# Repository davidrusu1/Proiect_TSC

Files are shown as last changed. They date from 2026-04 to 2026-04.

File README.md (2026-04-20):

# InkTime — Smartwatch Open Source

Un smartwatch proiectat de la zero — schematic, PCB 4 straturi, model 3D complet — bazat pe nRF52840 și un display E-Paper cu consum zero în standby.

---

## Despre proiect

InkTime este un ceas inteligent construit integral custom: fiecare componentă a fost aleasă, plasată și rutată manual, de la primul simbol în schematic până la modelul 3D pregătit pentru fabricație.

Tehnologia centrală este display-ul **E-Paper (e-ink)** — după ce afișează o imagine, o menține fără niciun consum de energie. Combinat cu modul deep sleep al nRF52840 (~1.5μA), dispozitivul poate funcționa zile întregi dintr-o baterie LiPo mică.

---

## Ce conține placa

| Subsistem | Componentă | Rol |
|---|---|---|
| Microcontroller | nRF52840 | Cortex-M4 64MHz, BT 5.0, USB nativ |
| Display | E-Paper via SPI | Afișaj fără consum în standby |
| Mișcare | BMA423 | Accelerometru 3 axe, step counter, wake-on-wrist |
| Încărcare | BQ25180 | LiPo charger programabil I2C, 5mA–1A |
| Alimentare | RT6160 | Buck-Boost 3.3V stabil indiferent de tensiunea bateriei |
| Fuel Gauge | MAX17048 | Monitorizare baterie ModelGauge, fără shunt rezistor |
| Feedback haptic | DRV2605 | Driver haptic I2C, 123 efecte ERM/LRA |
| USB | KH-TYPE-C-16P + USBLC6 | Conector USB-C cu protecție ESD ±15kV |
| Butoane | EVP-AKE31A ×3 | Butoane tactile SMD ultra-subțiri |
| RF | 2450AT18B100E | Antenă SMD 2.45GHz pentru Bluetooth |

---

## Diagrama bloc a sistemului

```
USB-C (5V)
    │
    ▼
┌─────────┐    VBUS      ┌──────────────┐
│  ESD    │─────────────▶│  BQ25180     │ LiPo Charger
│USBLC6   │              │  (I2C 0x6A)  │◀─── Baterie LiPo
└────┬────┘              └──────┬───────┘
     │ D+/D−                    │ VBAT
     │                          ▼
     │                   ┌──────────────┐
     │                   │  MAX17048    │ Fuel Gauge
     │                   │  (I2C 0x36)  │
     │                   └──────┬───────┘
     │                          │ VBAT
     │                          ▼
     │                   ┌──────────────┐
     │                   │   RT6160     │ Buck-Boost DC/DC
     │                   │  (I2C 0x62)  │─── 3V3 ──────────┐
     │                   └──────────────┘                   │
     │                                                      │
     └──────────────────────────────────────────────────────▼
                                                    ┌──────────────────┐
                  ┌── SPI ──▶ E-Paper Display       │                  │
                  │                                  │    nRF52840      │
                  ├── I2C ──▶ BMA423  (0x18)        │    Cortex-M4     │
                  │       ──▶ DRV2605 (0x5A)        │    64MHz / BT5.0 │
                  │       ──▶ BQ25180 (0x6A)        │                  │
                  │       ──▶ RT6160  (0x62)        └────────┬─────────┘
                  │       ──▶ MAX17048(0x36)                 │
                  │                                          │ GPIO
                  ├── SWD ──▶ TC2030-IDC                     │
                  │                                          ▼
                  └── USB ──▶ (intern nRF52840)      Butoane ×3 / IMU INT / HAPTIC_EN
```

---

## BOM — Bill of Materials

| Ref | Part Number | Descriere | Qty |
|---|---|---|---|
| U1 | nRF52840-QIAA-R | MCU ARM Cortex-M4, BT 5.0, USB 2.0, 1MB Flash | 1 |
| IC1 | BQ25180YBGR | LiPo charger liniar 1A I2C, 8-DSBGA | 1 |
| IC2 | DRV2605YZFR | Haptic driver ERM/LRA I2C 123 efecte, 9-BGA | 1 |
| IC3 | BMA423 | Accelerometru MEMS triaxial 12-bit, LGA-12 | 1 |
| U3 | MAX17048G+T10 | Fuel gauge ModelGauge 1-cell, SOT-23-6 | 1 |
| IC9 | RT6160AWSC | Buck-Boost DC/DC 800mA I2C, 15-WL-CSP | 1 |
| D3 | USBLC6-2SC6Y | TVS ESD ±15kV bidirecțional USB, SOT-23-6 | 1 |
| J4 | KH-TYPE-C-16P | Conector USB-C 16 pini SMD | 1 |
| J1 | 503480-2400 | Conector FPC/FFC 0.5mm pas 24 circuite | 1 |
| J2 | TC2030-IDC | Tag-Connect SWD 6 pini footprint-only | 1 |
| Q2 | DMG2305UX-7 | P-MOSFET 20V/4.2A, SOT-23 | 1 |
| Q3 | SI1308EDL-T1-GE3 | N-MOSFET 30V/1.5A, SC-70 | 1 |
| D1,D2,D5 | MBR0530 | Schottky 30V/500mA, SOD-123 | 3 |
| SW_* | EVP-AKE31A | Buton tactil SMD ultra-subțire Panasonic | 3 |
| ANT1 | 2450AT18B100E | Antenă SMD 2.45GHz Johanson | 1 |
| L7 | FTC252012SR47MBCA | Inductor 0.47μH SMD 2016 | 1 |
| L5 | 744043680 | Inductor 68μH WE-TPC SMD | 1 |
| X1 | SXT21410EC27-32.000M | Cristal SMD 32MHz | 1 |
| X2 | NX3215SA-32.768K | Cristal RTC 32.768kHz 3215 SMD | 1 |
| Cx | GJM0335C1ER33WB01D / GRM011R60J152KE01L | Condensatoare SMD 0201/0402, 1pF–22μF | ~50 |
| Rx | ERA-1AEB / CPF0201 | Rezistoare SMD 0201, 2.2Ω–10kΩ | ~15 |
| TP_* | — | Test pad SMD | 14 |

---

## Hardware în detaliu

### Cum circulă energia

Bateria LiPo (3.7–4.2V) furnizează tensiunea de intrare pentru regulatorul **RT6160**, care generează un rail stabil de 3.3V pentru întreaga placă. La conectarea USB-C, VBUS (5V) ajunge direct la **BQ25180**, care preia controlul încărcării bateriei independent de restul sistemului. nRF52840 monitorizează în permanență cele două stări: prezența USB prin semnalul CHARGER_PG și nivelul bateriei prin **MAX17048** pe magistrala I2C.

Componentele cu consum ridicat — display-ul E-Paper și driverul haptic — sunt controlate fiecare printr-un MOSFET (Q2/Q3), permițând nRF52840 să le întrerupă complet alimentarea când nu sunt necesare.

---

### Magistrala I2C — 5 periferice pe aceleași fire

| Componentă | Adresă I2C | Funcție |
|---|---|---|
| BQ25180 | 0x6A | Reglează curentul și tensiunea de încărcare |
| RT6160 | 0x62 | Ajustează tensiunea de ieșire la nevoie |
| BMA423 | 0x18 | Furnizează date accelerometru și numără pași |
| MAX17048 | 0x36 | Raportează procentul de baterie și tensiunea celulei |
| DRV2605 | 0x5A | Selectează și redă efecte tactile |

Clock pe **P0.06**, date pe **P0.07**. Rezistoare de pull-up pe ambele linii.

---

### SPI — Display E-Paper

Comunicație unidirecțională spre display — nu există linie MISO deoarece displayul nu transmite date înapoi. Frecvență maximă 4MHz. Pe lângă SCK și MOSI, display-ul necesită 3 semnale GPIO suplimentare: **DC** (Data/Command), **RST** (reset hardware) și **BUSY** (MCU-ul așteaptă când displayul procesează un refresh).

---

### SWD — Programare și debug

Conectorul **TC2030-IDC** (Tag-Connect, fără pini fizici pe PCB) expune SWDIO, SWDCLK, SWO și RESET. Nu ocupă înălțime în ansamblu — cablul de programare se atașează temporar prin spring pins pe pad-urile PCB-ului.

---

### Bluetooth și antenă

Antena **2450AT18B100E** este o antenă SMD ceramică pentru 2.4GHz, plasată spre exteriorul plăcii cu un decupaj în substrat sub ea. Decupajul elimină FR4-ul (material cu pierderi dielectrice la 2.4GHz) din zona de radiație, îmbunătățind câștigul și adaptarea de impedanță a antenei. Cristalul de 32MHz furnizează referința de frecvență pentru modulul radio.

---

### Cristalul de 32.768kHz — RTC în sleep

Al doilea oscilator alimentează timer-ul RTC al nRF52840 și rămâne activ inclusiv în deep sleep. Permite dispozitivului să mențină ora exactă și să se trezească la intervale precise fără a ține procesorul activ.

---

### BMA423 — Mai mult decât un accelerometru

BMA423 dispune de un procesor intern dedicat pentru algoritmii de step counting și wake-on-wrist, care rulează independent de nRF52840. La detectarea mișcării specifice ridicării mâinii, trimite o întrerupere pe **P1.08 (IMU_INT1)** care trezește MCU-ul din deep sleep în microsecunde. Consum în această stare: 0.9μA.

---

### Estimare consum și autonomie

| Scenariu | Curent estimat |
|---|---|
| nRF52840 TX Bluetooth activ | 6.26 mA |
| nRF52840 RX Bluetooth activ | 4.82 mA |
| Refresh display E-Paper | ~26 mA (câteva secunde) |
| BMA423 monitorizare continuă | 130 μA |
| MAX17048 fuel gauge activ | 23 μA |
| DRV2605 vibrație activă | 5 mA |
| nRF52840 deep sleep + RTC + BMA low-power | ~50–100 μA |

Consum mediu în utilizare normală (BT conectat periodic, refresh display la fiecare minut, IMU activ): **6–8 mA la 3.3V**.

Cu o baterie LiPo de **300mAh**: autonomie estimată **35–50 ore**.

---

## Alocarea pinilor nRF52840

### Display E-Paper (SPI)

| Pin MCU | Semnal | Direcție | Descriere |
|---|---|---|---|
| P0.02 / AIN0 | SCK | OUT | Clock SPI pentru display |
| P0.03 / AIN1 | MOSI | OUT | Date seriale spre display |
| P0.05 / AIN3 | EPD_CS | OUT | Chip select, activ LOW |
| P0.15 | EPD_RST | OUT | Reset hardware display, activ LOW |
| P0.16 | EPD_DC | OUT | LOW = comandă, HIGH = date |
| P0.17 | EPD_BUSY | IN | HIGH când displayul procesează |

### Periferice I2C

| Pin MCU | Semnal | Descriere |
|---|---|---|
| P0.06 | SCL | Clock comun pentru toate perifericele I2C |
| P0.07 | SDA | Date bidirecționale I2C |
| P0.08 | IMU_INT2 | Întrerupere secundară BMA423 (step counter) |
| P1.08 | IMU_INT1 | Întrerupere primară BMA423 (wake-on-wrist) |
| P0.10 / NFC2 | FUELGAUGE_ALT | Alarmă MAX17048 la baterie scăzută |
| P0.11 | CHARGER_PG | Power Good BQ25180 — HIGH când USB e valid |
| P0.12 | HAPTIC_EN | Enable DRV2605, activ HIGH |

### Butoane

| Pin MCU | Semnal | Descriere |
|---|---|---|
| P0.13 | BTN_UP | Buton sus (navigare meniu) |
| P0.14 | BTN_ENT | Buton enter / confirmare |
| P1.02 | BTN_DN | Buton jos (navigare meniu) |

### USB, SWD și ceasuri

| Pin MCU | Semnal | Interfață | Descriere |
|---|---|---|---|
| D+ | USB_DP | USB | Linie diferențială pozitivă, prin ESD |
| D− | USB_DM | USB | Linie diferențială negativă, prin ESD |
| VBUS | 5V_USB | PWR | Detecție USB prezent → BQ25180 |
| SWDIO | SWDIO | SWD | Date programare/debug |
| SWDCLK | SWDCLK | SWD | Clock programare/debug |
| SWO | SWO | SWD | Serial Wire Output (trace) |
| P0.18 / RESET | RESET | GPIO | Reset hardware MCU |
| ANT | RF | RF | Antenă Bluetooth 2.4GHz |
| XC1, XC2 | XTAL_32M | CLK | Cristal 32MHz — clock principal |
| XL1, XL2 | XTAL_32K | CLK | Cristal 32.768kHz — RTC sleep |

---

## PCB — Decizii de proiectare

### 4 straturi

| Strat | Conținut |
|---|---|
| L1 — Top | Toate componentele SMD + rutare semnale principale |
| L2 | Plan de masă GND continuu |
| L3 | Plan de alimentare 3V3 |
| L4 — Bottom | Rutare secundară + conexiuni via |

Planul de masă pe L2 direct sub stratul de semnal L1 minimizează inductanța buclei de return. Planul de 3V3 pe L3 reduce impedanța de alimentare, esențial pentru vârfurile de curent ale nRF52840 în modul TX.

### Decupaj sub antenă

FR4-ul este un material cu pierderi dielectrice la 2.4GHz. Un decupaj fizic al PCB-ului sub jumătatea neconectată a antenei 2450AT18B100E permite acesteia să radieze în aer, îmbunătățind performanța RF.

### Test pad-uri

14 test pad-uri distribuite pe semnalele: 3V3, VBAT, GND, SDA, SCL, SWDCLK, SWDIO, SWO, RESET, VREG. Permit conectarea unui multimetru sau logic analyzer după asamblare.

### Erori acceptate

- **Board Outline Clearance** — erorile generate de markerii de dimensiuni și textele de silkscreen aflate lângă marginea plăcii au fost aprobate, deoarece nu afectează fabricabilitatea PCB-ului.
- **Copper Width** pe traseele de sub componentele BGA — lățimea a fost redusă local pentru a permite rutarea prin pitch-ul mic al pad-urilor BGA, apoi adusă înapoi la 0.3mm după ieșirea din zona BGA.

---

## Ansamblu 3D

Modelat complet în Autodesk Fusion 360. Stratificarea de jos în sus:

```
┌─────────────────────────┐  ← Cadru superior + geam display
│     Display E-Paper     │  ← Panou e-ink + cablu FPC
│         PCB             │  ← Placa cu toate componentele
│      Baterie LiPo       │  ← Celulă lipită direct pe test pad-uri
└─────────────────────────┘  ← Carcasă inferioară
```

Butoanele (×3) sunt accesibile prin locașurile laterale ale carcasei. Conectorul USB-C iese prin fanta frontală. Shaker-ul haptic este montat în spațiul rămas lângă baterie.

---

## Galerie






---

## Structura repository-ului

```
InkTime/
│
├── Hardware/
│   ├── PCB.brd                  # Fișier board Fusion Electronics
│   ├── Schematic_Final.sch      # Schematic complet
│   └── Schematic_Final.pdf      # Export PDF schematic
│
├── Manufacturing/
│   ├── gerbers.zip              # Fișiere Gerber pentru fabricație
│   ├── InkTime.bom              # Bill of Materials
│   └── PnP_InkTime_front.cpl   # Pick & Place față
│
├── Mechanical/
│   ├── Exploded_Watch3D.zip    # Exported STEP ansamblu exploded view
│   └── Assembled Watch.f3z           # Proiect Autodesk Fusion 360
│
├── Images/                      # Randări și capturi PCB
│
├── LICENSE
└── README.md
```

---

MIT License — Copyright 2026 Rusu David Gabriel

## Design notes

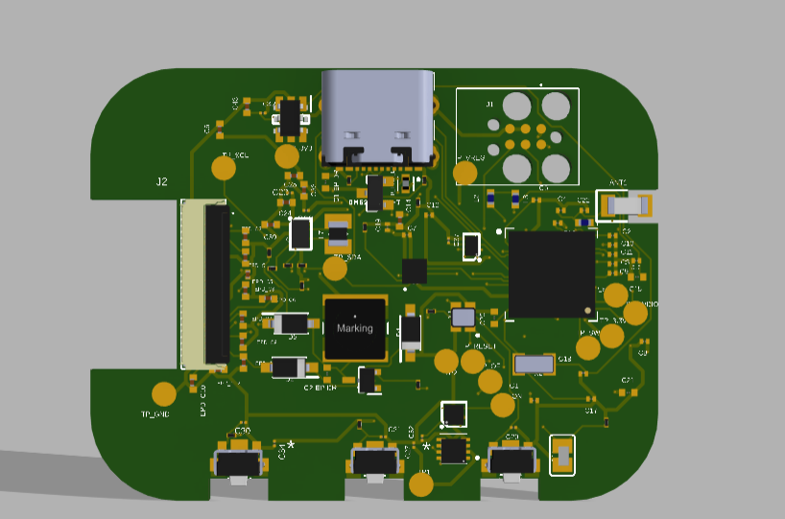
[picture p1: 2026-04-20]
Images/PCB3D Render.png

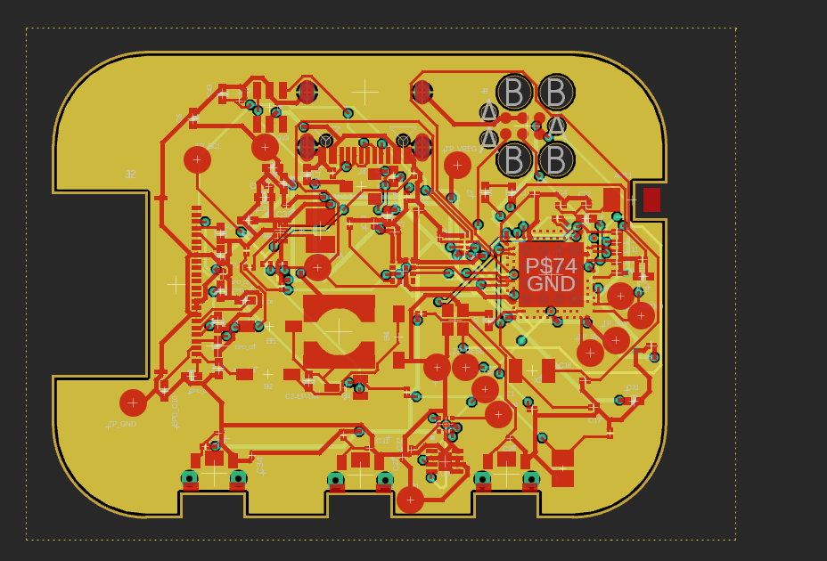
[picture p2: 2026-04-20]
Images/PCB2D.png

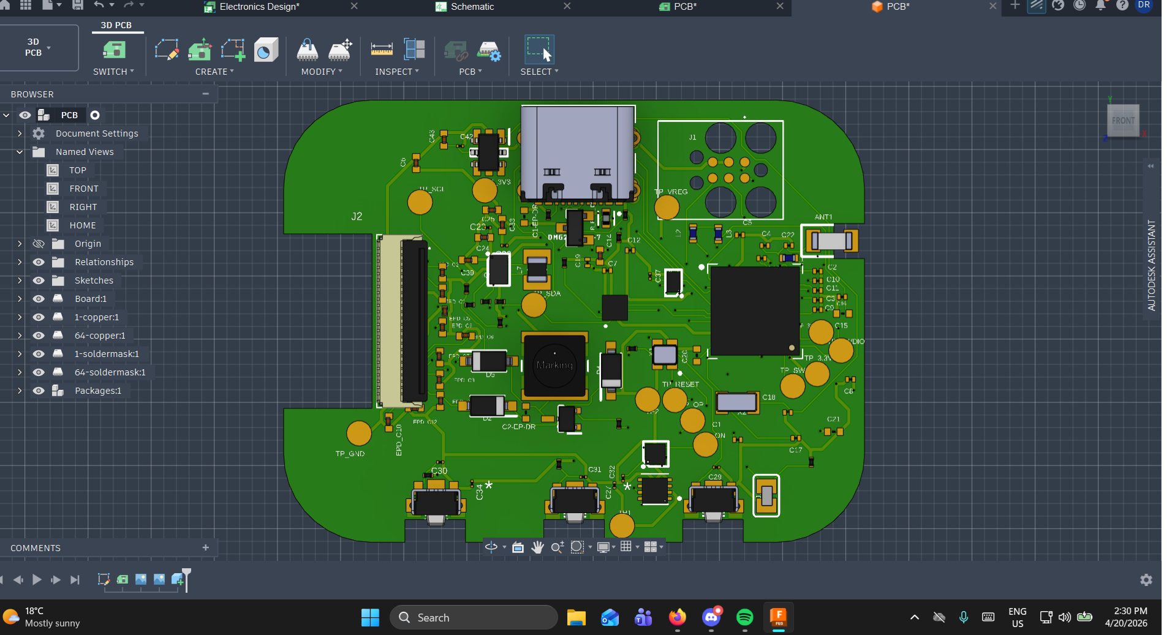
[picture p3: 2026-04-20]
Images/FrontView_PCB3D.png

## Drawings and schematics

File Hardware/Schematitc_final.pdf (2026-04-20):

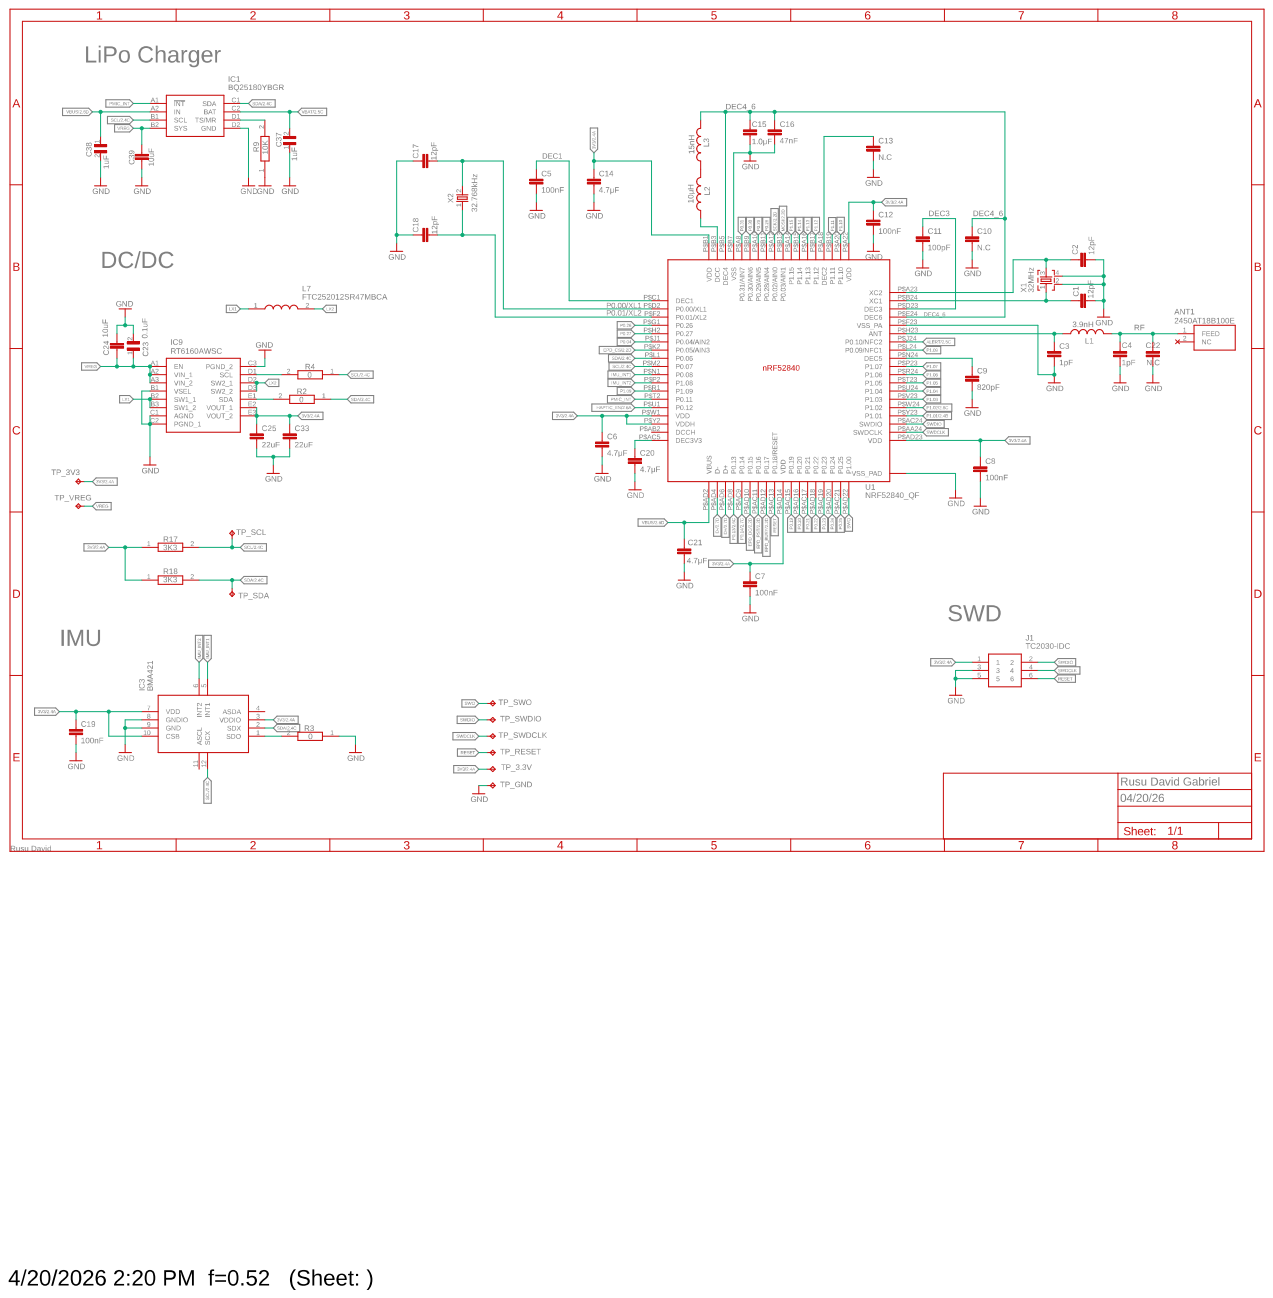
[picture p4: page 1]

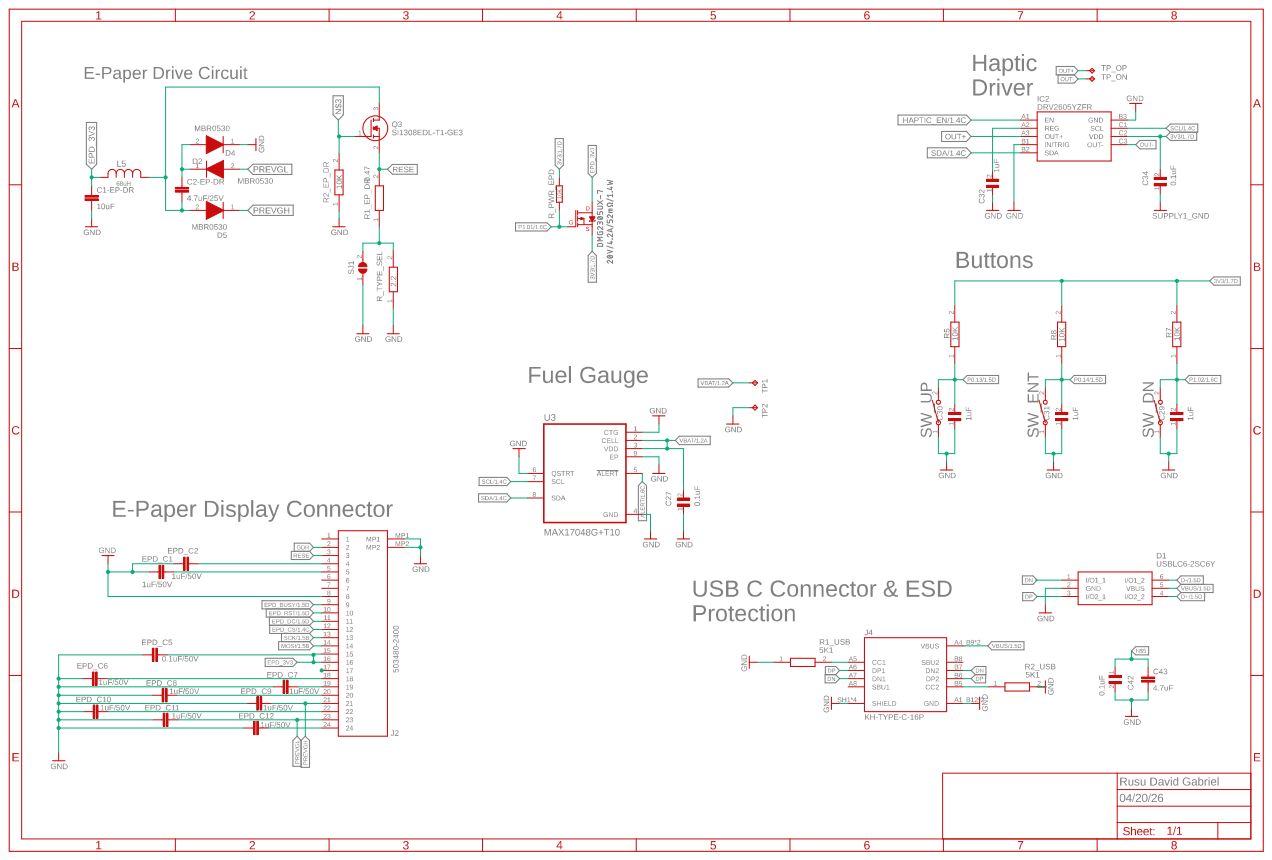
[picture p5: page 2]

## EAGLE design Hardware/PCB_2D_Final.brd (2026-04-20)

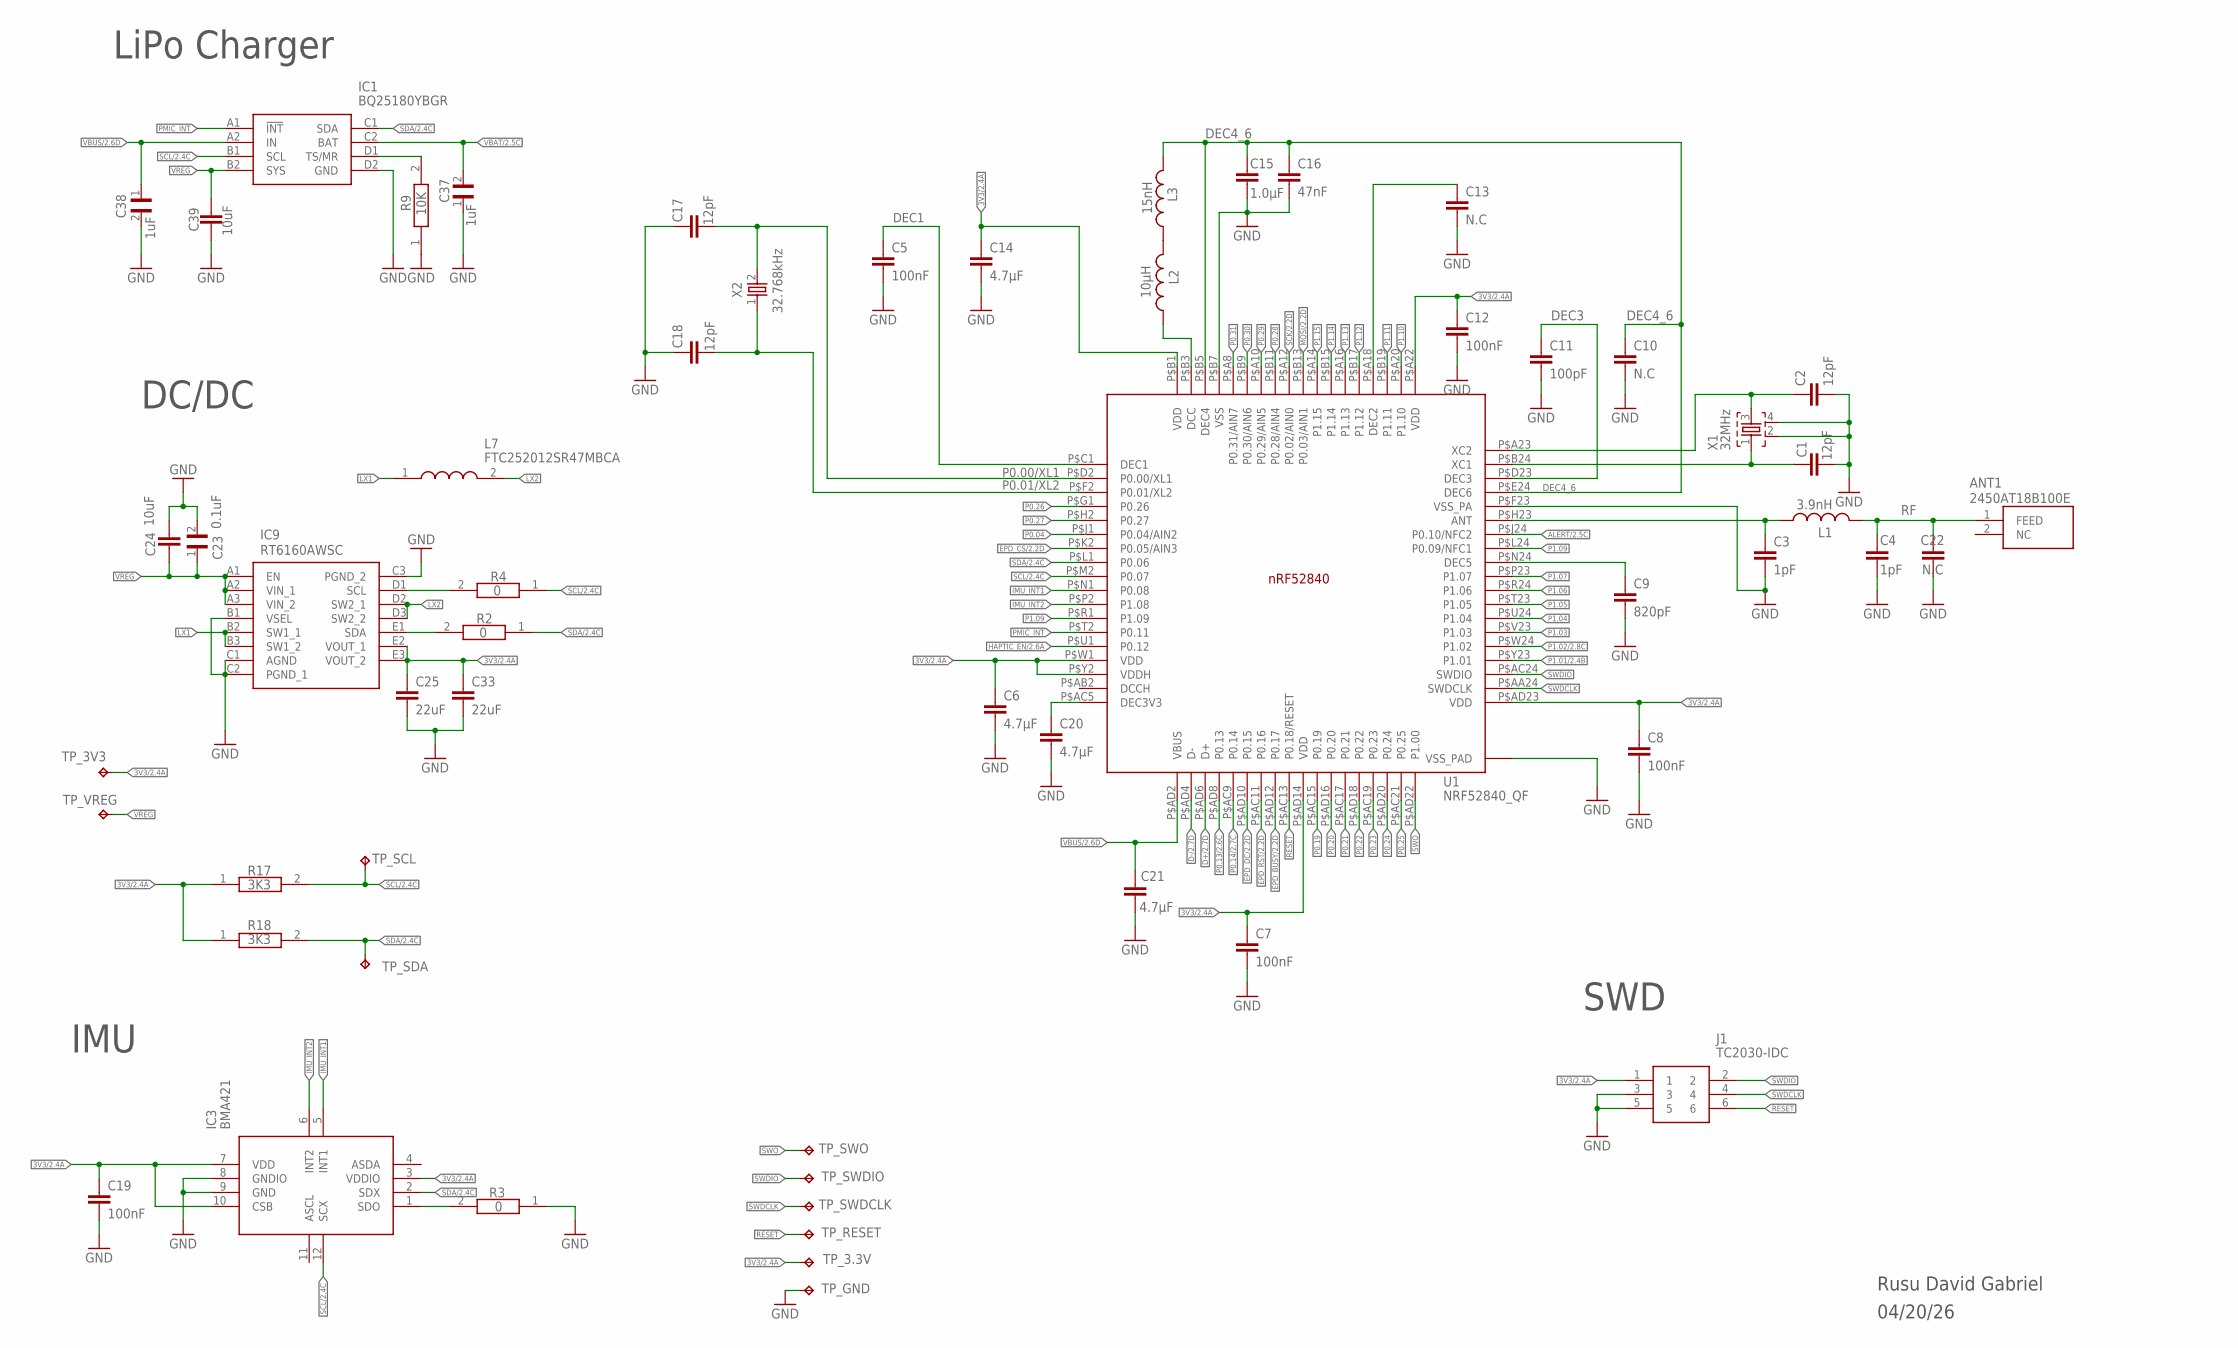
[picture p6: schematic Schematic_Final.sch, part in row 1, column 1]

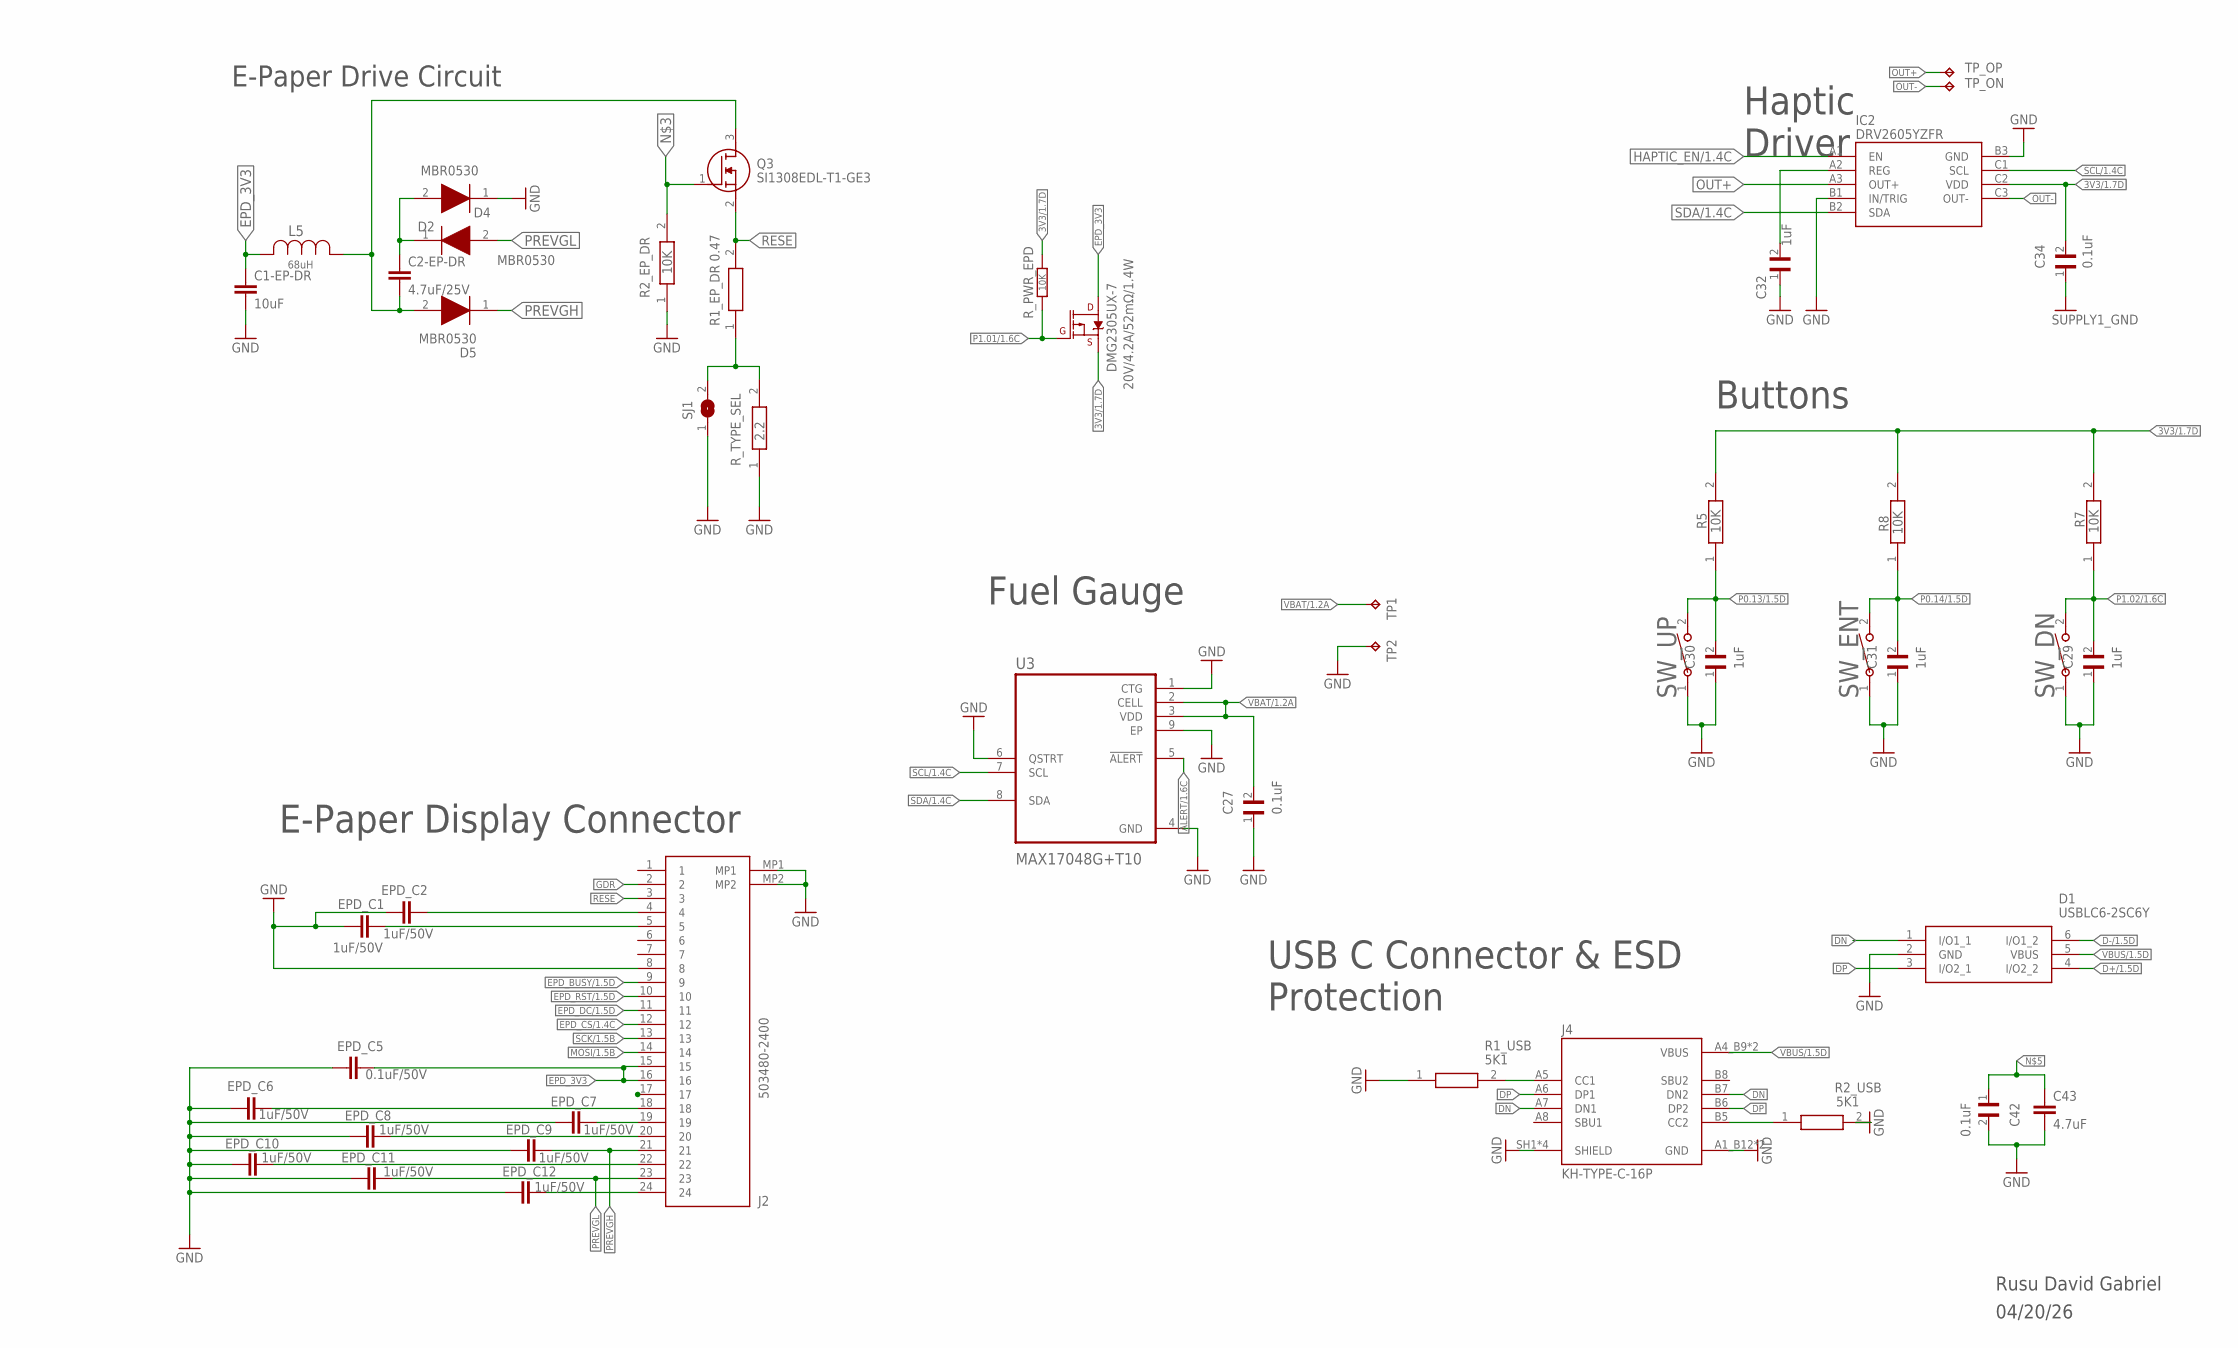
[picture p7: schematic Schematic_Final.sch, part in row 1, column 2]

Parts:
ANT1: 2450AT18B100E; 2450AT18B100E_ANTC3216X140N
C1, C2, C17, C18: 12pF; NORDIC_NRF_3_RESC0201_L
C1-EP-DR, C24, C39: 10uF; NORDIC_NRF_3_RESC0402_L
C2-EP-DR: 4.7uF/25V; NORDIC_NRF_3_RESC0402_L
C3, C4: 1pF; NORDIC_NRF_3_RESC0201_L
C5, C7, C8, C12, C19: 100nF; NORDIC_NRF_3_RESC0201_L
C6, C14, C20, C21: 4.7μF; NORDIC_NRF_3_RESC0402_L
C9: 820pF; NORDIC_NRF_3_RESC0201_L
C10, C13, C22: N.C; NORDIC_NRF_3_RESC0201_L
C11: 100pF; NORDIC_NRF_3_RESC0201_L
C15: 1.0μF; NORDIC_NRF_3_RESC0402_L
C16: 47nF; NORDIC_NRF_3_RESC0201_L
C23, C27, C34, C42: 0.1uF; GRM011R60J152KE01L_2_CAPC0201X13N
C25, C33: 22uF; NORDIC_NRF_3_RESC0402_L
C29, C30, C31, C32, C37, C38: 1uF; GRM011R60J152KE01L_2_CAPC0201X13N
C43: 4.7uF; NORDIC_NRF_3_RESC0402_L
D1: USBLC6-2SC6Y; ESP32_C6_LIBRARY_3_SOT95P280X145-6N
D2, D4, D5: MBR0530; ESP32_C6_LIBRARY_5_SOD3716X135N
DMG2305UX-7: 20V/4.2A/52mΩ/1.4W; ESP32_C6_LIBRARY_4_ESP32_C6_LIBRARY_4_ESP32_C6_LIBRARY_4_ES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
EPD_C1, EPD_C2, EPD_C6, EPD_C7, EPD_C8, EPD_C9, EPD_C10, EPD_C11, EPD_C12: 1uF/50V; NORDIC_NRF_3_RESC0402_L
EPD_C5: 0.1uF/50V; NORDIC_NRF_3_RESC0201_L
IC1: BQ25180YBGR; BQ25180YBGR_BGA8C40P2X4_100X155X50
IC2: DRV2605YZFR; DRV2605YZFR_BGA9C50P3X3_144X144X62
IC3: BMA421; BMA423_BMA423
IC9: RT6160AWSC; RT6160AWSC_BGA15C40P3X5_140X230X60
J1: TC2030-IDC; TC2030-IDC_TC2030IDC
J2: 503480-2400; 503480-2400_5034802400
J4: KH-TYPE-C-16P; KH-TYPE-C-16P_KINGHELM_KH-TYPE-C-16P
L1: 3.9nH; NORDIC_NRF_2_RESC0402_L
L2: 10μH; NORDIC_NRF_2_RESC0402_L
L3: 15nH; NORDIC_NRF_2_RESC0402_L
L5: 68uH; ESP32_C6_LIBRARY_2_IND_4828-WE-TPC_WRE
L7: FTC252012SR47MBCA; MLP2016SR47MT0S1_INDC2016X100N
Q3: SI1308EDL-T1-GE3; ESP32_C6_LIBRARY_6_SOT65P210X110-3N
R1_EP_DR: 0.47; CPF0201D7K68C1_0201
R1_USB, R2_USB: 5K1; CPF0201D7K68C1_0201
R2, R3, R4: 0; CPF0201D7K68C1_0201
R2_EP_DR, R5, R7, R8, R9: 10K; CPF0201D7K68C1_0201
R17, R18: 3K3; CPF0201D7K68C1_0201
R_PWR_EPD: 10K; RESC1005X40
R_TYPE_SEL: 2.2; CPF0201D7K68C1_0201
SJ1: ESP32_C6_LIBRARY_7_JUMPER_SJ
SW_DN: 2025-10-22_07-23-44_LIBRARY_EVP-AKE31ASW_EVP-AKE3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; 2025-10-22_07-23-44_LIBRARY_SW_EVP-AKE31A_PAN
SW_ENT: 2025-10-22_07-23-44_LIBRARY_EVP-AKE31ASW_EVP-AKE3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; 2025-10-22_07-23-44_LIBRARY_SW_EVP-AKE31A_PAN
SW_UP: 2025-10-22_07-23-44_LIBRARY_EVP-AKE31ASW_EVP-AKE3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; 2025-10-22_07-23-44_LIBRARY_SW_EVP-AKE31A_PAN
TP1, TP2: HECTOR_WATCH_1_TPTP20R; HECTOR_WATCH_1_TP20R
TP_3.3V, TP_3V3: HECTOR_WATCH_1_TPTP20R; HECTOR_WATCH_1_TP20R
TP_GND: HECTOR_WATCH_1_TPTP20R; HECTOR_WATCH_1_TP20R
TP_ON: HECTOR_WATCH_1_TPTP20R; HECTOR_WATCH_1_TP20R
TP_OP: TP_OP; HECTOR_WATCH_1_TP20R
TP_RESET: HECTOR_WATCH_1_TPTP20R; HECTOR_WATCH_1_TP20R
TP_SCL: HECTOR_WATCH_1_TPTP20R; HECTOR_WATCH_1_TP20R
TP_SDA: HECTOR_WATCH_1_TPTP20R; HECTOR_WATCH_1_TP20R
TP_SWDCLK: HECTOR_WATCH_1_TPTP20R; HECTOR_WATCH_1_TP20R
TP_SWDIO: HECTOR_WATCH_1_TPTP20R; HECTOR_WATCH_1_TP20R
TP_SWO: HECTOR_WATCH_1_TPTP20R; HECTOR_WATCH_1_TP20R
TP_VREG: HECTOR_WATCH_1_TPTP20R; HECTOR_WATCH_1_TP20R
U1: NRF52840_QF; NORDIC_NRF_4_AQFN50P700X700X85_HS-74N
U3: MAX17048G+T10; ESP32_C6_LIBRARY_SON50P200X200X80-9N
X1: 32MHz; NORDIC_NRF_BT-XTAL_2016_N
X2: 32.768kHz; NORDIC_NRF_1_XTAL_3215_N

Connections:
3V3/1.7D: C34.2, DMG2305UX-7.2 (S), IC2.C2 (VDD), R5.2, R7.2, R8.2, R_PWR_EPD.2
3V3/2.4A: C6.1, C7.1, C8.1, C12.1, C14.1, C19.1, C25.1, C33.1, IC3.3 (VDDIO), IC3.7 (VDD), IC3.10 (CSB), IC9.E2 (VOUT_1), IC9.E3 (VOUT_2), J1.1, R17.1, R18.1, TP_3.3V.TP, TP_3V3.TP, U1.P$A22 (VDD), U1.P$AD14 (VDD), U1.P$AD23 (VDD), U1.P$B1 (VDD), U1.P$W1 (VDD), U1.P$Y2 (VDDH)
ALERT/1.6C: U3.5 (!ALERT)
ALERT/2.5C: U1.P$J24 (P0.10/NFC2)
D+/1.5D: D1.4 (I/O2_2)
D+/2.7D: U1.P$AD6 (D+)
D-/1.5D: D1.6 (I/O1_2)
D-/2.7D: U1.P$AD4 (D-)
DEC1: C5.1, U1.P$C1 (DEC1)
DEC3: C11.1, U1.P$D23 (DEC3)
DEC4_6: C10.1, C15.1, C16.1, L3.2, U1.P$B5 (DEC4), U1.P$E24 (DEC6)
DN: D1.1 (I/O1_1), J4.A7 (DN1), J4.B7 (DN2)
DP: D1.3 (I/O2_1), J4.A6 (DP1), J4.B6 (DP2)
EPD_3V3: C1-EP-DR.1, DMG2305UX-7.3 (D), EPD_C5.2, J2.15, J2.16, L5.2
EPD_BUSY/1.5D: J2.9
EPD_BUSY/2.2D: U1.P$AD12 (P0.17)
EPD_CS/1.4C: J2.12
EPD_CS/2.2D: U1.P$K2 (P0.05/AIN3)
EPD_DC/1.5D: J2.11
EPD_DC/2.2D: U1.P$AD10 (P0.15)
EPD_RST/1.5D: J2.10
EPD_RST/2.2D: U1.P$AC11 (P0.16)
GDR: J2.2
GND: C1.2, C1-EP-DR.2, C2.2, C3.2, C4.2, C5.2, C6.2, C7.2, C8.2, C9.2, C10.2, C11.2, C12.2, C13.2, C14.2, C15.2, C16.2, C17.1, C18.1, C19.2, C20.2, C21.2, C22.2, C23.2, C24.1, C25.2, C27.1, C29.1, C30.1, C31.1, C32.1, C33.2, C34.1, C37.1, C38.2, C39.2, C42.2, C43.2, D1.2 (GND), D4.1 (K), EPD_C1.1, EPD_C2.1, EPD_C5.1, EPD_C6.1, EPD_C7.1, EPD_C8.1, EPD_C9.1, EPD_C10.1, EPD_C11.1, EPD_C12.1, IC1.D2 (GND), IC2.B1 (IN/TRIG), IC2.B3 (GND), IC3.8 (GNDIO), IC3.9 (GND), IC9.B1 (VSEL), IC9.C1 (AGND), IC9.C2 (PGND_1), IC9.C3 (PGND_2), J1.3, J1.5, J2.8, J2.17, J2.MP1, J2.MP2, J4.A1_B12 (GND), J4.A12_B1 (GND), J4.SH1 (SHIELD), J4.SH2 (SHIELD), J4.SH3 (SHIELD), J4.SH4 (SHIELD), R1_USB.1, R2_EP_DR.1, R2_USB.2, R3.1, R9.1, R_TYPE_SEL.1, SJ1.1, SW_DN.1, SW_ENT.1, SW_UP.1, TP2.TP, TP_GND.TP, U1.P$74 (VSS_PAD), U1.P$75 (VSS_PAD), U1.P$76 (VSS_PAD), U1.P$77 (VSS_PAD), U1.P$78 (VSS_PAD), U1.P$79 (VSS_PAD), U1.P$80 (VSS_PAD), U1.P$81 (VSS_PAD), U1.P$82 (VSS_PAD), U1.P$83 (VSS_PAD), U1.P$84 (VSS_PAD), U1.P$85 (VSS_PAD), U1.P$86 (VSS_PAD), U1.P$87 (VSS_PAD), U1.P$88 (VSS_PAD), U1.P$89 (VSS_PAD), U1.P$90 (VSS_PAD), U1.P$B7 (VSS), U1.P$F23 (VSS_PA), U3.1 (CTG), U3.4 (GND), U3.6 (QSTRT), U3.9 (EP), X1.2, X1.4
HAPTIC_EN/1.4C: IC2.A1 (EN)
HAPTIC_EN/2.6A: U1.P$U1 (P0.12)
IMU_INT1: IC3.5 (INT1), U1.P$N1 (P0.08)
IMU_INT2: IC3.6 (INT2), U1.P$P2 (P1.08)
LX1: IC9.B2 (SW1_1), IC9.B3 (SW1_2), L7.1
LX2: IC9.D2 (SW2_1), IC9.D3 (SW2_2), L7.2
MOSI/1.5B: J2.14
MOSI/2.2D: U1.P$B13 (P0.03/AIN1)
unnamed: IC9.D1 (SCL), R4.2
unnamed: IC3.1 (SDO), R3.2
unnamed: IC9.E1 (SDA), Q3.1 (G), R2.2, R2_EP_DR.2
unnamed: C2-EP-DR.2, D5.2 (A), L5.1, Q3.3 (D)
unnamed: C42.1, C43.1, IC1.D1 (TS/MR), R9.2
unnamed: C2-EP-DR.1, D2.1 (K), D4.2 (A)
unnamed: R1_EP_DR.1, R_TYPE_SEL.2, SJ1.2
unnamed: C32.2, IC2.A2 (REG)
unnamed: J4.A5 (CC1), R1_USB.2
unnamed: EPD_C2.2, J2.4
unnamed: EPD_C1.2, J2.5
unnamed: J4.B5 (CC2), R2_USB.1
unnamed: C20.1, U1.P$AC5 (DEC3V3)
unnamed: EPD_C6.2, J2.18
unnamed: EPD_C7.2, J2.19
unnamed: EPD_C8.2, J2.20
unnamed: EPD_C10.2, J2.22
unnamed: EPD_C12.2, J2.24
unnamed: C9.1, U1.P$N24 (DEC5)
unnamed: C3.1, L1.1, U1.P$H23 (ANT)
unnamed: C2.1, U1.P$A23 (XC2), X1.3
unnamed: C1.1, U1.P$B24 (XC1), X1.1
unnamed: C13.1, U1.P$A18 (DEC2)
unnamed: L2.1, U1.P$B3 (DCC)
unnamed: L2.2, L3.1
OUT+: IC2.A3 (OUT+), TP_OP.TP
OUT-: IC2.C3 (OUT-), TP_ON.TP
P0.00/XL1: C17.2, U1.P$D2 (P0.00/XL1), X2.2
P0.01/XL2: C18.2, U1.P$F2 (P0.01/XL2), X2.1
P0.04: U1.P$J1 (P0.04/AIN2)
P0.13/1.5D: C30.2, R5.1, SW_UP.2
P0.13/2.6C: U1.P$AD8 (P0.13)
P0.14/1.5D: C31.2, R8.1, SW_ENT.2
P0.14/2.7C: U1.P$AC9 (P0.14)
P0.19: U1.P$AC15 (P0.19)
P0.20: U1.P$AD16 (P0.20)
P0.21: U1.P$AC17 (P0.21)
P0.22: U1.P$AD18 (P0.22)
P0.23: U1.P$AC19 (P0.23)
P0.24: U1.P$AD20 (P0.24)
P0.25: U1.P$AC21 (P0.25)
P0.26: U1.P$G1 (P0.26)
P0.27: U1.P$H2 (P0.27)
P0.28: U1.P$B11 (P0.28/AIN4)
P0.29: U1.P$A10 (P0.29/AIN5)
P0.30: U1.P$B9 (P0.30/AIN6)
P0.31: U1.P$A8 (P0.31/AIN7)
P1.01/1.6C: DMG2305UX-7.1 (G), R_PWR_EPD.1
P1.01/2.4B: U1.P$Y23 (P1.01)
P1.02/1.6C: C29.2, R7.1, SW_DN.2
P1.02/2.8C: U1.P$W24 (P1.02)
P1.03: U1.P$V23 (P1.03)
P1.04: U1.P$U24 (P1.04)
P1.05: U1.P$T23 (P1.05)
P1.06: U1.P$R24 (P1.06)
P1.07: U1.P$P23 (P1.07)
P1.09: U1.P$L24 (P0.09/NFC1), U1.P$R1 (P1.09)
P1.10: U1.P$A20 (P1.10)
P1.11: U1.P$B19 (P1.11)
P1.12: U1.P$B17 (P1.12)
P1.13: U1.P$A16 (P1.13)
P1.14: U1.P$B15 (P1.14)
P1.15: U1.P$A14 (P1.15)
PMIC_INT: IC1.A1 (!INT), U1.P$T2 (P0.11)
PREVGH: D5.1 (K), EPD_C9.2, J2.21
PREVGL: D2.2 (A), EPD_C11.2, J2.23
RESE: J2.3, Q3.2 (S), R1_EP_DR.2
RESET: J1.6, TP_RESET.TP, U1.P$AC13 (P0.18/RESET)
RF: ANT1.1 (FEED), C4.1, C22.1, L1.2
SCK/1.5B: J2.13
SCK/2.2D: U1.P$A12 (P0.02/AIN0)
SCL/1.4C: IC2.C1 (SCL), U3.7 (SCL)
SCL/2.4C: IC1.B1 (SCL), IC3.12 (SCX), R4.1, R17.2, TP_SCL.TP, U1.P$M2 (P0.07)
SDA/1.4C: IC2.B2 (SDA), U3.8 (SDA)
SDA/2.4C: IC1.C1 (SDA), IC3.2 (SDX), R2.1, R18.2, TP_SDA.TP, U1.P$L1 (P0.06)
SWDCLK: J1.4, TP_SWDCLK.TP, U1.P$AA24 (SWDCLK)
SWDIO: J1.2, TP_SWDIO.TP, U1.P$AC24 (SWDIO)
SWO: TP_SWO.TP, U1.P$AD22 (P1.00)
VBAT/1.2A: C27.2, TP1.TP, U3.2 (CELL), U3.3 (VDD)
VBAT/2.5C: C37.2, IC1.C2 (BAT)
VBUS/1.5D: D1.5 (VBUS), J4.A4_B9 (VBUS), J4.A9_B4 (VBUS)
VBUS/2.6D: C21.1, C38.1, IC1.A2 (IN), U1.P$AD2 (VBUS)
VREG: C23.1, C24.2, C39.1, IC1.B2 (SYS), IC9.A1 (EN), IC9.A2 (VIN_1), IC9.A3 (VIN_2), TP_VREG.TP

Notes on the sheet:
LiPo Charger
DC/DC
IMU
SWD
E-Paper Drive Circuit
Fuel Gauge
E-Paper Display Connector
Buttons
Haptic Driver
USB C Connector & ESD Protection
Rusu David Gabriel
04/20/26

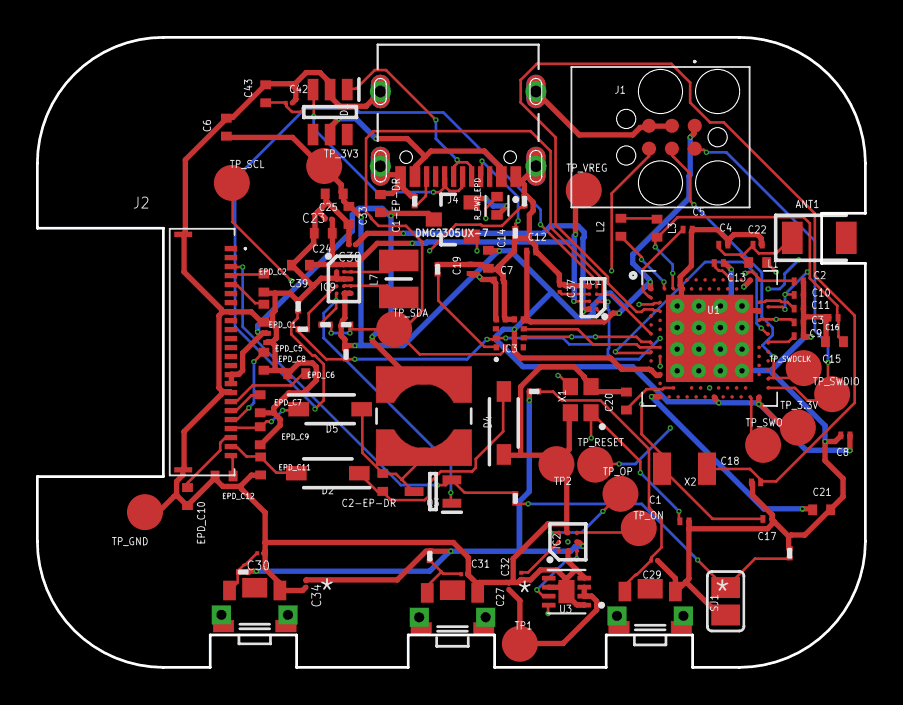
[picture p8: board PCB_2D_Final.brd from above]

Board: 4 copper layers, 46.0 x 35.0 mm, 105 parts (0 on the bottom side), 65 nets.

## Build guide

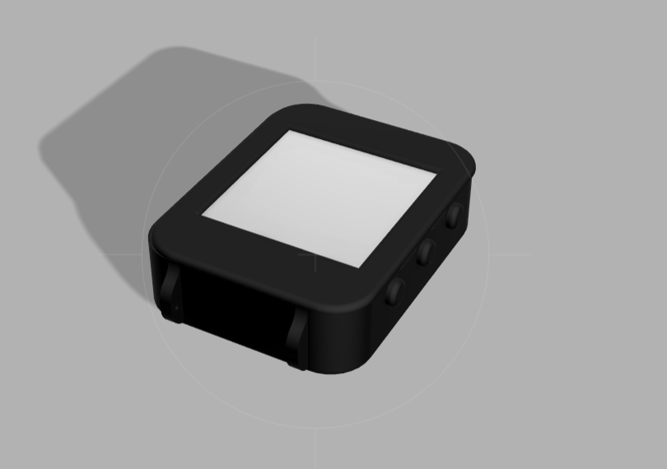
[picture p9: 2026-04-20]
Images/Assembled.png

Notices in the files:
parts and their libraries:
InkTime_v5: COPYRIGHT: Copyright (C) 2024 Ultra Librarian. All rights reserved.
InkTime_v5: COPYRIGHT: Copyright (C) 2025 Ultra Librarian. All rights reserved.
